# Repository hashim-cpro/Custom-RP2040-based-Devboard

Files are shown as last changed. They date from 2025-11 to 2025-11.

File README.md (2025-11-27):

# RP2040 Based Custom Devboard

This is a rp2040 based devboard based on the pico dimensions with complete battery management and usb c connectivity.
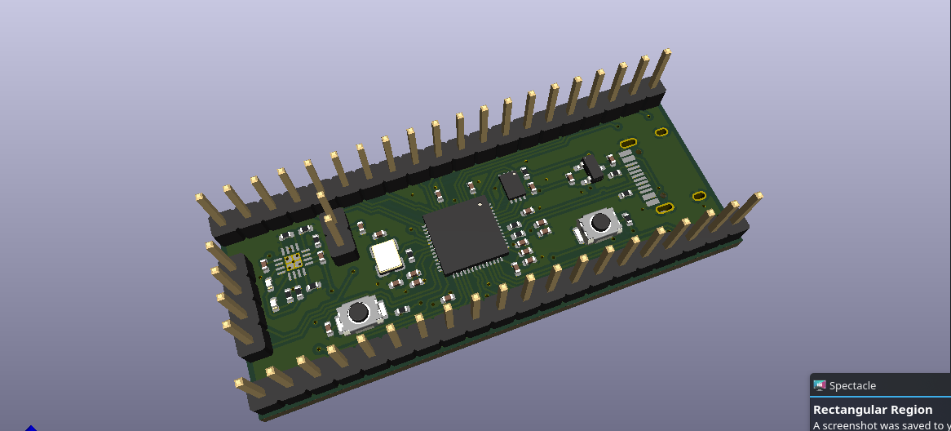
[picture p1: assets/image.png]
Board Image


## Features

- RP2040 Microcontroller
- USB-C Connectivity
- Battery Management System
- Multiple GPIO Pins
- Onboard LEDs
- Onboard Buttons
- Compact Design

## Schematic

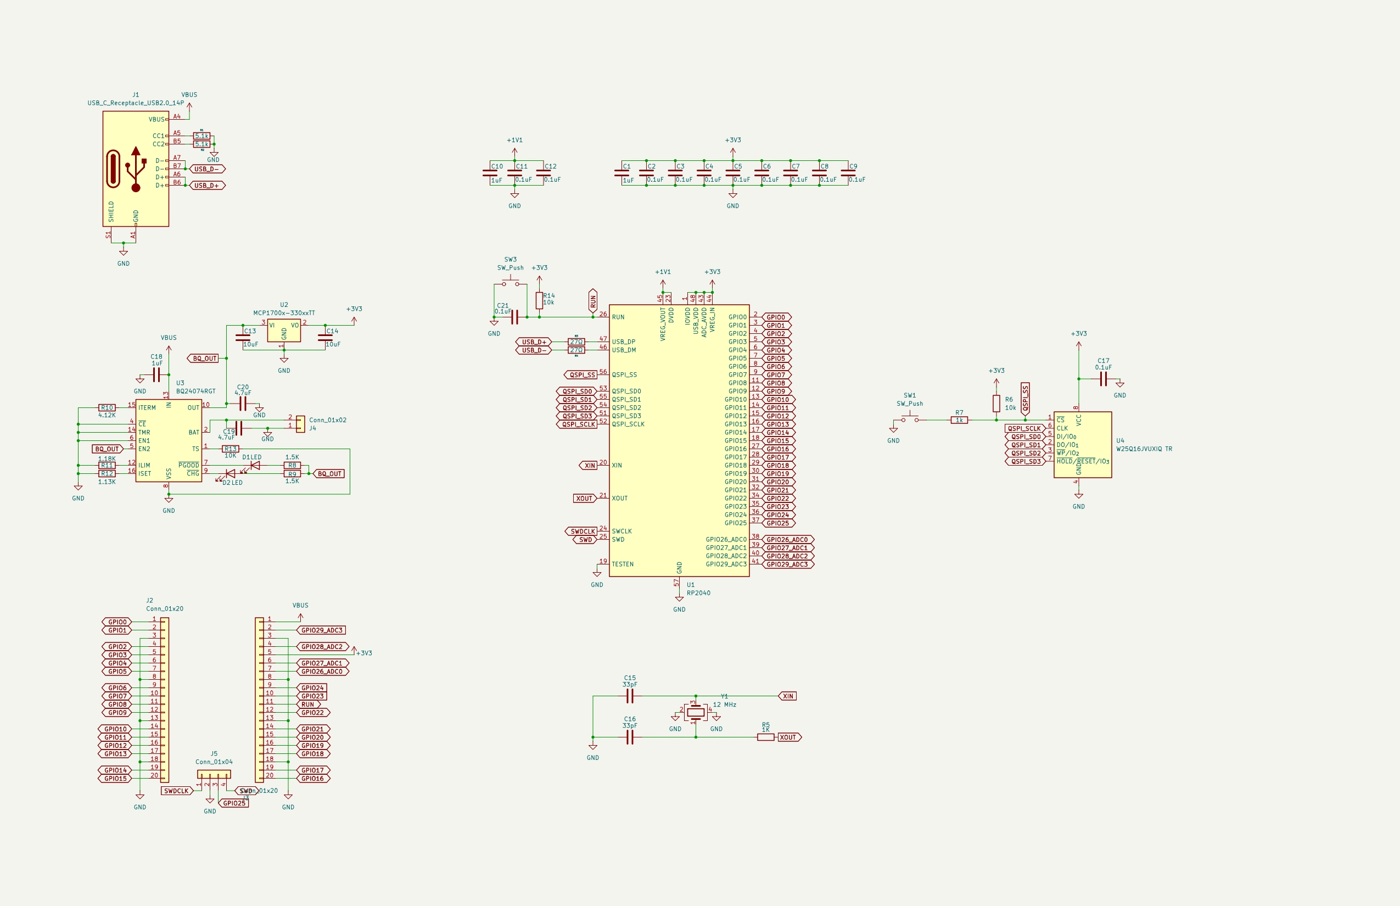
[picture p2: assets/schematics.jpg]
Schematic Image


## PCB

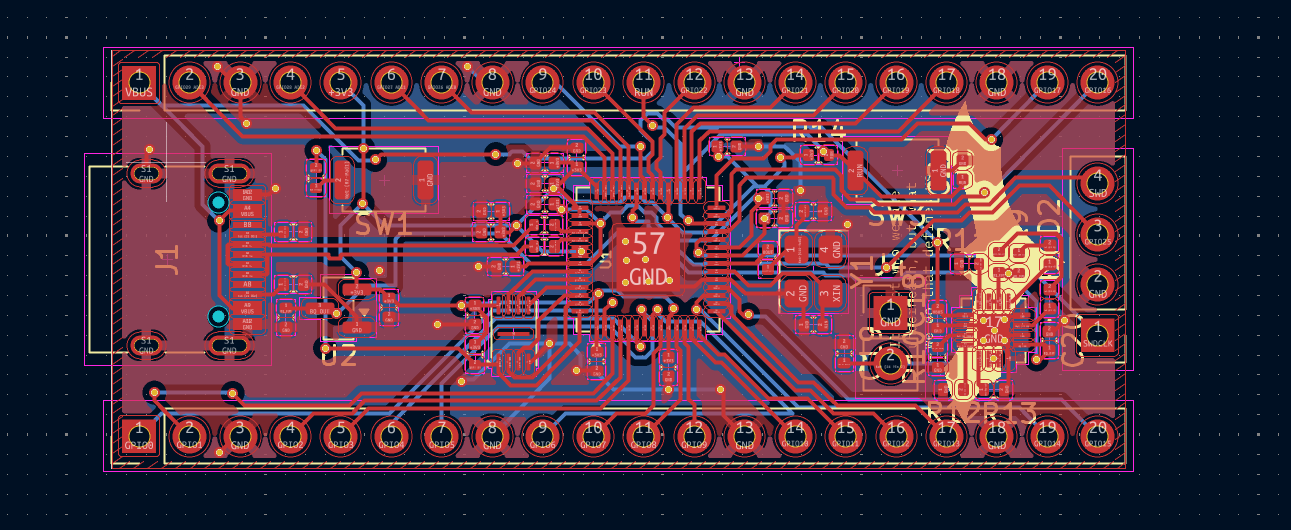
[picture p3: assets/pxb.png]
PCB Image


## Bill of Materials (BOM)

The complete LCSC BOM with all components can be found [here](/LCSC%20BOM.csv).

### Cost Breakdown

| Item | Cost (USD) |
| --- | --- |
| **Components (LCSC)**  | $15.17 |
| Components Shipping | $11.09 |
| **PCB (JLCPCB)** | $4.10 |
| PCB Shipping | $8.32 |
| **Total Project Cost** | **$38.68** |

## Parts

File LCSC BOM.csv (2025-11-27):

Index | LCSC# | MPN | Manufacturer | Package | Customer # | Description | RoHS | Quantity | MOQ | Multiple | Unit Price($) | Extended Price($) | Product Link
1 | C52923 | CL05A105KA5NQNC | Samsung Electro-Mechanics | 0402 |  | 25V 1uF X5R ±10% 0402 Ceramic Capacitors RoHS | yes | 100 | 100 | 100 | 0.0030 | 0.30 | https://www.lcsc.com/product-detail/C52923.html
2 | C15525 | CL05A106MQ5NUNC | Samsung Electro-Mechanics | 0402 |  | 6.3V 10uF X5R ±20% 0402 Ceramic Capacitors RoHS | yes | 100 | 100 | 100 | 0.0047 | 0.47 | https://www.lcsc.com/product-detail/C15525.html
3 | C1562 | 0402CG330J500NT | FH | 0402 |  | 50V 33pF C0G ±5% 0402 Ceramic Capacitors RoHS | yes | 100 | 100 | 100 | 0.0010 | 0.10 | https://www.lcsc.com/product-detail/C1562.html
4 | C1525 | CL05B104KO5NNNC | Samsung Electro-Mechanics | 0402 |  | 16V 100nF X7R ±10% 0402 Ceramic Capacitors RoHS | yes | 100 | 100 | 100 | 0.0012 | 0.12 | https://www.lcsc.com/product-detail/C1525.html
5 | C23733 | CL05A475MP5NRNC | Samsung Electro-Mechanics | 0402 |  | 10V 4.7uF X5R ±20% 0402 Ceramic Capacitors RoHS | yes | 50 | 50 | 50 | 0.0048 | 0.24 | https://www.lcsc.com/product-detail/C23733.html
6 | C965793 | XL-1005UGC | XINGLIGHT | 0402 |  | 25mA 249mcd Top-mount 516nm~531nm Emerald Green 3V 80mW 0402 LED Indication - Discrete RoHS | yes | 100 | 100 | 100 | 0.0069 | 0.69 | https://www.lcsc.com/product-detail/C965793.html
7 | C165948 | TYPE-C-31-M-12 | Korean Hroparts Elec | SMD |  | 1 16P Type-C SMD USB, DVI, HDMI Connector Assemblies RoHS | yes | 5 | 5 | 5 | 0.1752 | 0.88 | https://www.lcsc.com/product-detail/C165948.html
8 | C25905 | 0402WGF5101TCE | UNI-ROYAL | 0402 |  | 5.1kΩ 62.5mW 50V ±100ppm/℃ Thick Film Resistor ±1% 0402 Chip Resistor - Surface Mount RoHS | yes | 100 | 100 | 100 | 0.0005 | 0.05 | https://www.lcsc.com/product-detail/C25905.html
9 | C25100 | 0402WGF270JTCE | UNI-ROYAL | 0402 |  | 27Ω 62.5mW 50V ±100ppm/℃ Thick Film Resistor ±1% 0402 Chip Resistor - Surface Mount RoHS | yes | 100 | 100 | 100 | 0.0006 | 0.06 | https://www.lcsc.com/product-detail/C25100.html
10 | C11702 | 0402WGF1001TCE | UNI-ROYAL | 0402 |  | 1kΩ 62.5mW 50V ±100ppm/℃ Thick Film Resistor ±1% 0402 Chip Resistor - Surface Mount RoHS | yes | 100 | 100 | 100 | 0.0006 | 0.06 | https://www.lcsc.com/product-detail/C11702.html
11 | C25867 | 0402WGF1501TCE | UNI-ROYAL | 0402 |  | 62.5mW 1.5kΩ 50V ±100ppm/℃ Thick Film Resistor ±1% 0402 Chip Resistor - Surface Mount RoHS | yes | 100 | 100 | 100 | 0.0006 | 0.06 | https://www.lcsc.com/product-detail/C25867.html
12 | C60081 | 0402WGF4121TCE | UNI-ROYAL | 0402 |  | 62.5mW 4.12kΩ 50V ±100ppm/℃ Thick Film Resistor ±1% 0402 Chip Resistor - Surface Mount RoHS | yes | 100 | 100 | 100 | 0.0004 | 0.04 | https://www.lcsc.com/product-detail/C60081.html
13 | C159137 | RTT021181FTH | RALEC | 0402 |  | 1.18kΩ 62.5mW 50V ±100ppm/℃ Thick Film Resistor ±1% 0402 Chip Resistor - Surface Mount RoHS | yes | 100 | 100 | 100 | 0.0005 | 0.05 | https://www.lcsc.com/product-detail/C159137.html
14 | C67014 | 0402WGF1131TCE | UNI-ROYAL | 0402 |  | 1.13kΩ 62.5mW 50V ±100ppm/℃ Thick Film Resistor ±1% 0402 Chip Resistor - Surface Mount RoHS | yes | 100 | 100 | 100 | 0.0006 | 0.06 | https://www.lcsc.com/product-detail/C67014.html
15 | C25744 | 0402WGF1002TCE | UNI-ROYAL | 0402 |  | 10kΩ 62.5mW 50V ±100ppm/℃ Thick Film Resistor ±1% 0402 Chip Resistor - Surface Mount RoHS | yes | 100 | 100 | 100 | 0.0006 | 0.06 | https://www.lcsc.com/product-detail/C25744.html
16 | C720477 | TS-1088-AR02016 | XUNPU | SMD,4x3mm |  | Without Bracket 4mm 12V 3mm Round Button SPST 50mA SMD,4x3mm Tactile Switches RoHS | yes | 10 | 10 | 10 | 0.0418 | 0.42 | https://www.lcsc.com/product-detail/C720477.html
17 | C2040 | RP2040 | Raspberry Pi | LQFN-56(7x7) |  | 133MHz 30 LQFN-56(7x7) Microcontrollers RoHS | yes | 2 | 1 | 1 | 0.9482 | 1.90 | https://www.lcsc.com/product-detail/C2040.html
18 | C39051 | MCP1700T-3302E/TT | MICROCHIP | SOT-23 |  | 44dB@(100Hz) Positive Fixed 3.3V SOT-23 Voltage Regulators - Linear, Low Drop Out (LDO) Regulators RoHS | yes | 5 | 5 | 5 | 0.4067 | 2.03 | https://www.lcsc.com/product-detail/C39051.html
19 | C2861252 | BQ24074RGTT | TI | VQFN-16-EP(3x3) |  | 4.35V~10.5V Lithium Battery 1 1.5A VQFN-16-EP(3x3) Battery Chargers ICs RoHS | yes | 2 | 1 | 1 | 2.9489 | 5.90 | https://www.lcsc.com/product-detail/C2861252.html
20 | C2843335 | W25Q16JVUXIQ | Winbond | USON-8-EP(2x3) |  | 16Mbit 2.7V~3.6V 133MHz SPI USON-8-EP(2x3) Memory (ICs) RoHS | yes | 2 | 1 | 1 | 0.4944 | 0.99 | https://www.lcsc.com/product-detail/C2843335.html
21 | C9002 | X322512MSB4SI | YXC Crystal Oscillators | SMD3225-4P |  | Crystal Oscillator 20pF SMD3225-4P Crystals RoHS | yes | 10 | 10 | 10 | 0.0669 | 0.67 | https://www.lcsc.com/product-detail/C9002.html

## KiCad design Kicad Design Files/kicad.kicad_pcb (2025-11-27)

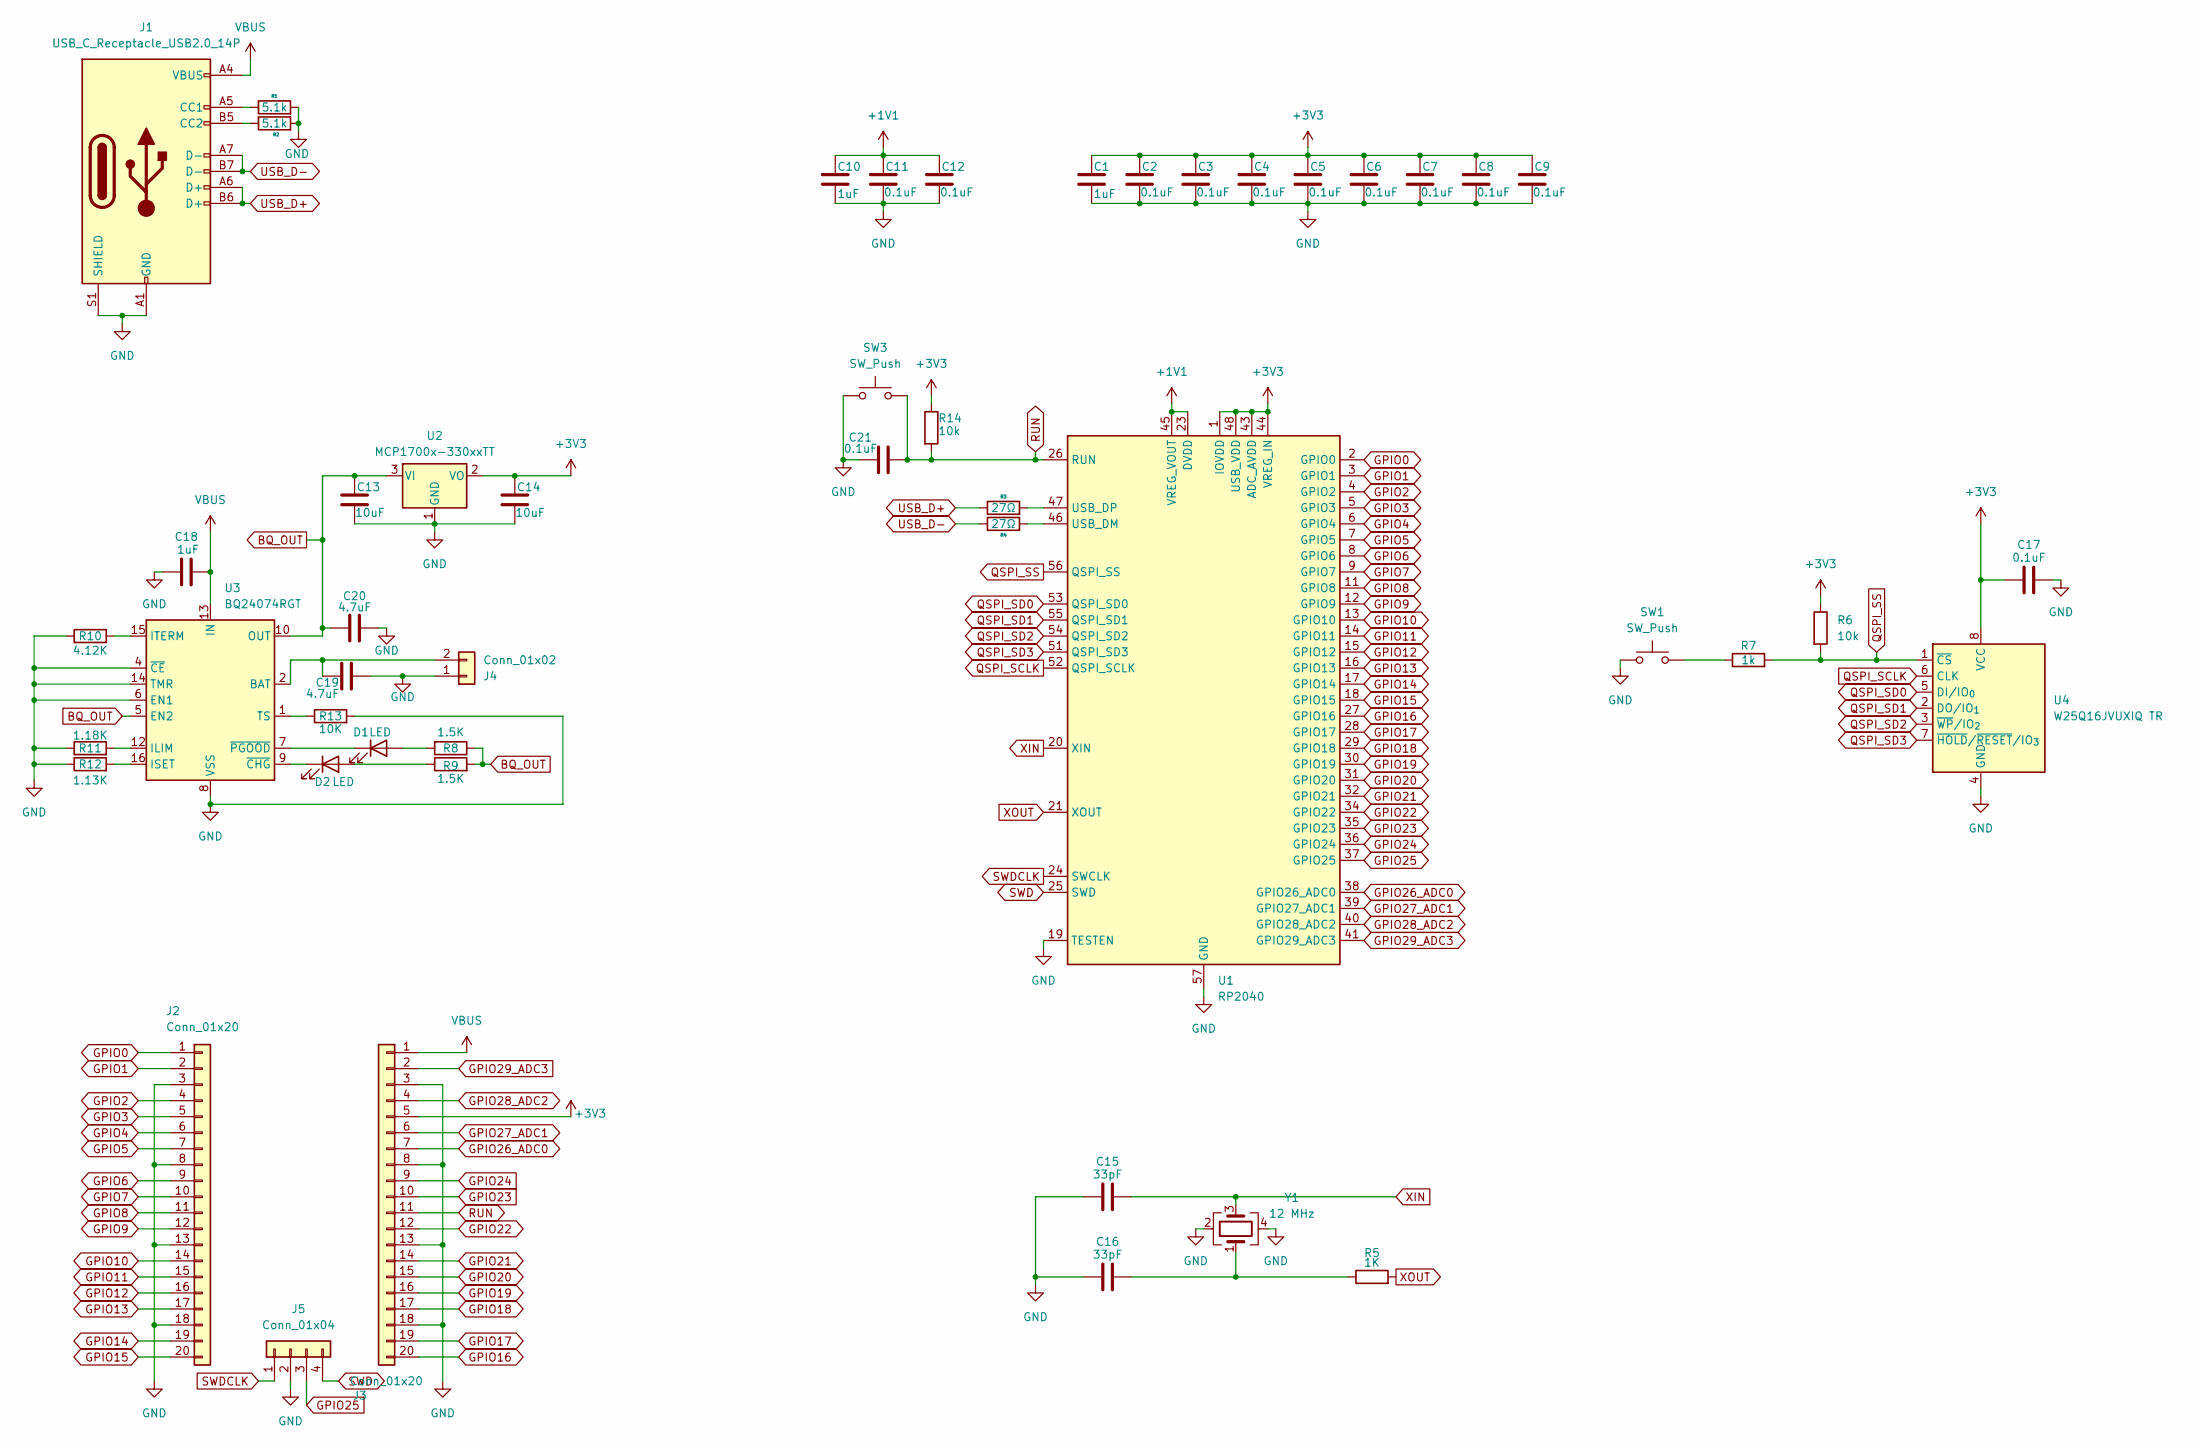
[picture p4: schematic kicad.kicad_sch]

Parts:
C1, C10, C18: 1uF; C_0402_1005Metric
C2, C3, C4, C5, C6, C7, C8, C9, C11, C12, C17, C21: 0.1uF; C_0402_1005Metric
C13, C14: 10uF; C_0402_1005Metric
C15, C16: 33pF; C_0402_1005Metric
C19, C20: 4.7uF; C_0402_1005Metric
D1, D2: LED; LED_0402_1005Metric
J1: USB_C_Receptacle_USB2.0_14P; USB_C_Receptacle_HRO_TYPE-C-31-M-12
J2, J3: Conn_01x20; PinHeader_1x20_P2.54mm_Vertical
J4: Conn_01x02; PinHeader_1x02_P2.54mm_Vertical
J5: Conn_01x04; PinHeader_1x04_P2.54mm_Vertical
R1, R2: 5.1k; R_0402_1005Metric
R3, R4: 27Ω; R_0402_1005Metric
R5: 1K; R_0402_1005Metric
R6, R14: 10k; R_0402_1005Metric
R7: 1k; R_0402_1005Metric
R8, R9: 1.5K; R_0402_1005Metric
R10: 4.12K; R_0402_1005Metric
R11: 1.18K; R_0402_1005Metric
R12: 1.13K; R_0402_1005Metric
R13: 10K; R_0402_1005Metric
SW1, SW3: SW_Push; SW_Push_SPST_NO_Alps_SKRK
U1: RP2040; QFN-56-1EP_7x7mm_P0.4mm_EP3.2x3.2mm
U2: MCP1700x-330xxTT; SOT-23
U3: BQ24074RGT; VQFN-16-1EP_3x3mm_P0.5mm_EP1.6x1.6mm
U4: W25Q16JVUXIQ TR; Winbond_USON-8-1EP_3x2mm_P0.5mm_EP0.2x1.6mm
Y1: 12 MHz; Crystal_SMD_3225-4Pin_3.2x2.5mm

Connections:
+1V1: C10.1, C11.1, C12.1, U1.23 (DVDD), U1.45 (VREG_VOUT), U1.50 (DVDD)
+3V3: C1.1, C2.1, C3.1, C4.1, C5.1, C6.1, C7.1, C8.1, C9.1, C14.1, C17.1, J3.5, R6.1, R14.1, U1.1 (IOVDD), U1.10 (IOVDD), U1.22 (IOVDD), U1.33 (IOVDD), U1.42 (IOVDD), U1.43 (ADC_AVDD), U1.44 (VREG_IN), U1.48 (USB_VDD), U1.49 (IOVDD), U2.2 (VO), U4.8 (VCC)
BQ_OUT: C13.1, C20.1, R8.1, R9.2, U2.3 (VI), U3.5 (EN2), U3.10 (OUT), U3.11 (OUT)
GND: C1.2, C2.2, C3.2, C4.2, C5.2, C6.2, C7.2, C8.2, C9.2, C10.2, C11.2, C12.2, C13.2, C14.2, C15.1, C16.1, C17.2, C18.1, C19.2, C20.2, C21.2, J1.A1 (GND), J1.A12 (GND), J1.B1 (GND), J1.B12 (GND), J1.S1 (SHIELD), J2.3, J2.8, J2.13, J2.18, J3.3, J3.8, J3.13, J3.18, J4.1, J5.2, R1.2, R2.2, R10.1, R11.1, R12.1, R13.2, SW1.1, SW3.1, U1.19 (TESTEN), U1.57 (GND), U2.1 (GND), U3.4 (~CE), U3.6 (EN1), U3.8 (VSS), U3.14 (TMR), U3.17 (VSS), U4.4 (GND), Y1.2, Y1.4
GPIO0: J2.1, U1.2 (GPIO0)
GPIO1: J2.2, U1.3 (GPIO1)
GPIO2: J2.4, U1.4 (GPIO2)
GPIO3: J2.5, U1.5 (GPIO3)
GPIO4: J2.6, U1.6 (GPIO4)
GPIO5: J2.7, U1.7 (GPIO5)
GPIO6: J2.9, U1.8 (GPIO6)
GPIO7: J2.10, U1.9 (GPIO7)
GPIO8: J2.11, U1.11 (GPIO8)
GPIO9: J2.12, U1.12 (GPIO9)
GPIO10: J2.14, U1.13 (GPIO10)
GPIO11: J2.15, U1.14 (GPIO11)
GPIO12: J2.16, U1.15 (GPIO12)
GPIO13: J2.17, U1.16 (GPIO13)
GPIO14: J2.19, U1.17 (GPIO14)
GPIO15: J2.20, U1.18 (GPIO15)
GPIO16: J3.20, U1.27 (GPIO16)
GPIO17: J3.19, U1.28 (GPIO17)
GPIO18: J3.17, U1.29 (GPIO18)
GPIO19: J3.16, U1.30 (GPIO19)
GPIO20: J3.15, U1.31 (GPIO20)
GPIO21: J3.14, U1.32 (GPIO21)
GPIO22: J3.12, U1.34 (GPIO22)
GPIO23: J3.10, U1.35 (GPIO23)
GPIO24: J3.9, U1.36 (GPIO24)
GPIO25: J5.3, U1.37 (GPIO25)
GPIO26_ADC0: J3.7, U1.38 (GPIO26_ADC0)
GPIO27_ADC1: J3.6, U1.39 (GPIO27_ADC1)
GPIO28_ADC2: J3.4, U1.40 (GPIO28_ADC2)
GPIO29_ADC3: J3.2, U1.41 (GPIO29_ADC3)
unnamed: C16.2, R5.1, Y1.1
unnamed: D1.2 (A), R8.2
unnamed: D1.1 (K), U3.7 (~PGOOD)
unnamed: D2.2 (A), R9.1
unnamed: D2.1 (K), U3.9 (~CHG)
unnamed: J1.A5 (CC1), R1.1
unnamed: J1.B5 (CC2), R2.1
unnamed: C19.1, J4.2, U3.2 (BAT), U3.3 (BAT)
unnamed: R7.1, SW1.2
unnamed: R4.2, U1.46 (USB_DM)
unnamed: R3.2, U1.47 (USB_DP)
unnamed: R11.2, U3.12 (ILIM)
unnamed: R12.2, U3.16 (ISET)
unnamed: R10.2, U3.15 (ITERM)
unnamed: R13.1, U3.1 (TS)
QSPI_SCLK: U1.52 (QSPI_SCLK), U4.6 (CLK)
QSPI_SD0: U1.53 (QSPI_SD0), U4.5 (DI/IO_{0})
QSPI_SD1: U1.55 (QSPI_SD1), U4.2 (DO/IO_{1})
QSPI_SD2: U1.54 (QSPI_SD2), U4.3 (~WP/IO_{2})
QSPI_SD3: U1.51 (QSPI_SD3), U4.7 (~HOLD/~RESET/IO_{3})
QSPI_SS: R6.2, R7.2, U1.56 (QSPI_SS), U4.1 (~CS)
RUN: C21.1, J3.11, R14.2, SW3.2, U1.26 (RUN)
SWD: J5.4, U1.25 (SWD)
SWDCLK: J5.1, U1.24 (SWCLK)
USB_D+: J1.A6 (D+), J1.B6 (D+), R3.1
USB_D-: J1.A7 (D-), J1.B7 (D-), R4.1
VBUS: C18.2, J1.A4 (VBUS), J1.A9 (VBUS), J1.B4 (VBUS), J1.B9 (VBUS), J3.1, U3.13 (IN)
XIN: C15.2, U1.20 (XIN), Y1.3
XOUT: R5.2, U1.21 (XOUT)

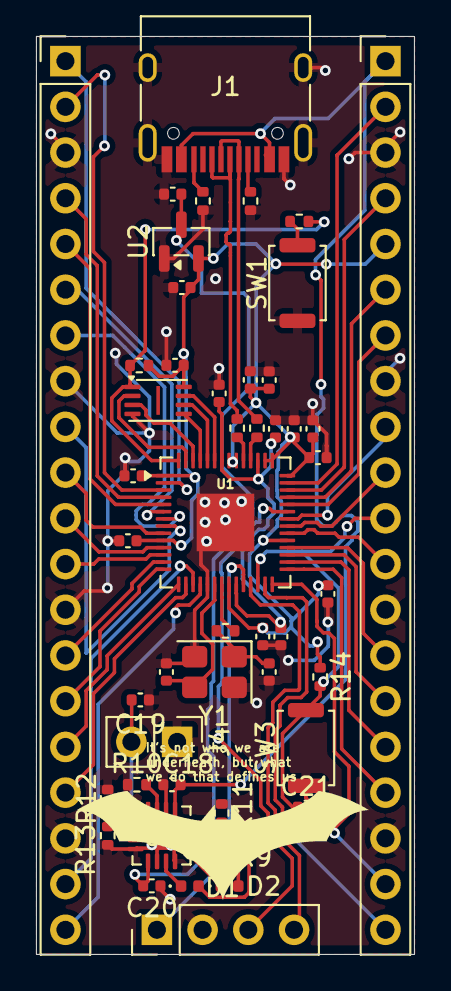
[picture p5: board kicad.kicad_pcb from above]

Board: 2 copper layers, 21.0 x 51.0 mm, 49 parts (0 on the bottom side), 63 nets.

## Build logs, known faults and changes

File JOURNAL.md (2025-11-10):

<!--
  ===================    !!READ THIS NOTICE!!   ====================
  DO NOT edit this file manually. Your changes WILL BE OVERWRITTEN!
  This journal is auto generated and updated by Hack Club Blueprint.
  To edit this file, please edit your journal entries on Blueprint.
  ==================================================================
-->

## 11/7/2025 - Started the Project Schematic and handled everything power   




well i just set up the project in kicad and started the shcematics. I am done with the power decoupling part on the MCU and also wired up the USB type C and connected it to the MCU.

## 11/8/2025 - complted the schematics  

i just wired the oscillator and these quartz crystals are interesting🤔 also added memory and IO and just like that our schematics are finished! :yay


got some errors in ERC and fixed them as well


## 11/9/2025 - Placed the PCB parts  

So changed a couple of parts in the schematics and assigned the footprints and placed the main components with 0.00 mm symmetry. Didin't placed the decoupling capacitots yet and some resistors as well. 


## 11/10/2025 2 AM - Started Routing the PCB  

Started routing the PCB and i can say i did it pretty rough. I placed the capicitors and resistors little too close to the rp2040 which made everything tight and i also used alot of vias for this as well. 




## 11/10/2025 4 PM - Completed the Routiong  

Completed the Routing, had to move the capacitors and some components here and there to make space for traces because i placed them to close to the MCU. Now it is almost done but there are alot of errors that i need to fix **😭**



## 11/10/2025 9 PM - Finished the PCB  

So just finished up the PCB and i fixed all the errors in the DRC and now there are no errors finally :yay Most of the errors i got were thermal relief errors that i fixed by adding vias and changing some settings for the ground fillings and stuff.
